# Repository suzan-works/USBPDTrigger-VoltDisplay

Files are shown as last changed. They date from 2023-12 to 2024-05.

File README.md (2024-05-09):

# 電圧表示付き USB PD トリガー
 WCH CH32X035 マイコンを使用して、Vbus電圧をSSD1306 OLEDモジュールに表示する、USB PDトリガーデバイスです。  
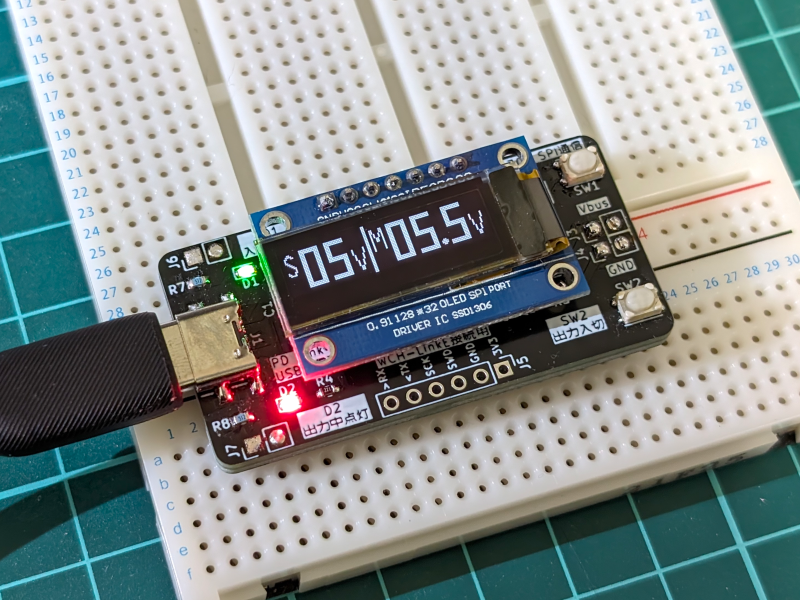
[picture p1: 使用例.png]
使用例
 

# 紹介動画
(https://www.youtube.com/watch?v=RrcGVxVSbrM)

# 操作手順
1. USB-CコネクタにUSB PD電源を接続します。
1. 電圧切替スイッチで出力電圧を変更します。(5→9→12→15→20Vのループ)
1. OLEDディスプレイで希望の電圧が出ていることを確認します。
1. 出力入切スイッチを押すと基板右端のヘッダピンから出力されます。  

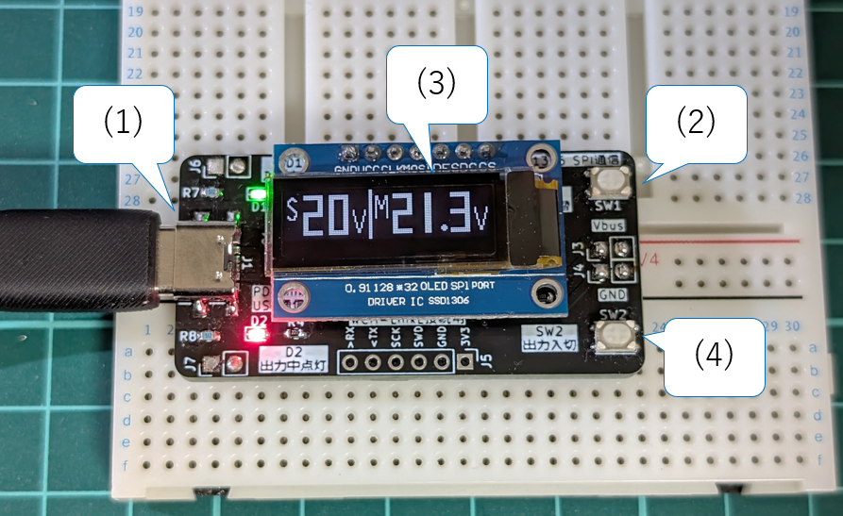
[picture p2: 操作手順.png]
操作手順


# 注意
- 出力電圧はUSB電源(USB PD Source)の仕様に依存します。設定電圧とVbus電圧が乖離する場合があります。
- 表示されるVbus電圧は目安で、測定器としての精度を保証するものではありません。
- 出力電流は1A程度を想定して設計しています。
- このデバイスの使用における損害は一切保証いたしません。自己責任でご使用ください。

# 販売
[boothにて販売中](https://suzan-works.booth.pm/items/5385432)

# マイコン開発
Arduino IDEでのファームウェア変更が可能です。  
WCH LinkEエミュレーターでPCに接続して、「ボードマネージャ」＞「CH32V EVT Boards Support」＞「CH32X035」を選択します。  
参考情報  
https://github.com/openwch/arduino_core_ch32  
https://youtu.be/PSXAfMaWH_A?si=gFLTGL1ydqfZDPP8  

# 設計資料 v1.0
## 回路図
- 回路図 [PDF](回路図.pdf) [KiCanvas](https://kicanvas.org/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)  
- BOM

|Reference|Value|ECサイト|コメント|
|:----|:----|:----|:----|
|U1|マイコン<br>CH32X035G8U6| | |
|U2|三端子レギュレータ<br>NJM78L33SU3|https://akizukidenshi.com/catalog/g/gI-11319/| |
|J1|USB Type-Cコネクタ 電源供給用|https://akizukidenshi.com/catalog/g/gC-16438/|コネクタの固定用ピンをカットして実装しています|
|J2|OLEDディスプレイ<br>SSD1306 SPI 128x32 0.91インチ| | |
|J3, J4, J6, J7|ピンヘッダ 2.54mmピッチ|https://akizukidenshi.com/catalog/g/gC-00167/| |
|J5|WCH-LinkE| | |
|C1, C2|1u/50V/2012|https://akizukidenshi.com/catalog/g/gP-15331/| |
|C3|1u/25V/1608|https://akizukidenshi.com/catalog/g/gP-14526/| |
|R1, R4|220/1608/±5%| | |
|R2|10k/1608/±1%|https://www.marutsu.co.jp/pc/i/857775/| |
|R3|1k/1608/±1%|https://www.marutsu.co.jp/pc/i/857774/| |
|R5|10k/1608/±5%| | |
|R6|22k/1608/±5%| | |
|R7, R8|5.1k/1608/±5%| | |
|D1|緑チップLED<br>SML-E12P8WT86|https://akizukidenshi.com/catalog/g/gI-11878/| |
|D2|赤チップLED<br>SML-E12V8WT86|https://akizukidenshi.com/catalog/g/gI-11879/| |
|F1|ポリスイッチ<br>microSMD010|https://akizukidenshi.com/catalog/g/gP-01316/| |
|Q1, Q2|Pch MOSFET<br>AO3401A|https://akizukidenshi.com/catalog/g/gI-14654/| |
|Q3|抵抗入りトランジスタ<br>DTC143ZU3HZGT106|https://akizukidenshi.com/catalog/g/gI-16746/|基板フットプリントが間違っており無理やり実装しています|
|SW1, SW2|タクトスイッチ<br>SKRPABE010|https://akizukidenshi.com/catalog/g/gP-06184/| |

## プリント基板
- 基板CAD [KiCanvas](https://kicanvas.org/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)
- 外観写真  
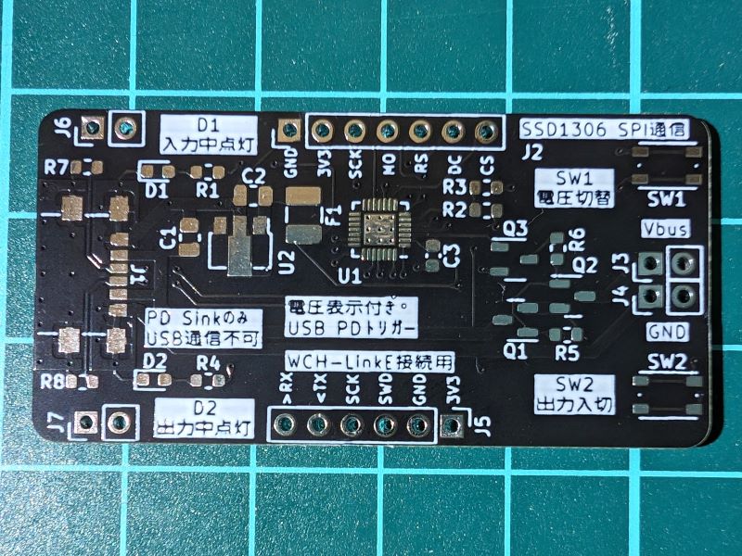
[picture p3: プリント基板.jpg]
プリント基板


## ファームウェア
- ファームウェア [inoファイル](USBPDTrigger-VoltDisplay.ino)

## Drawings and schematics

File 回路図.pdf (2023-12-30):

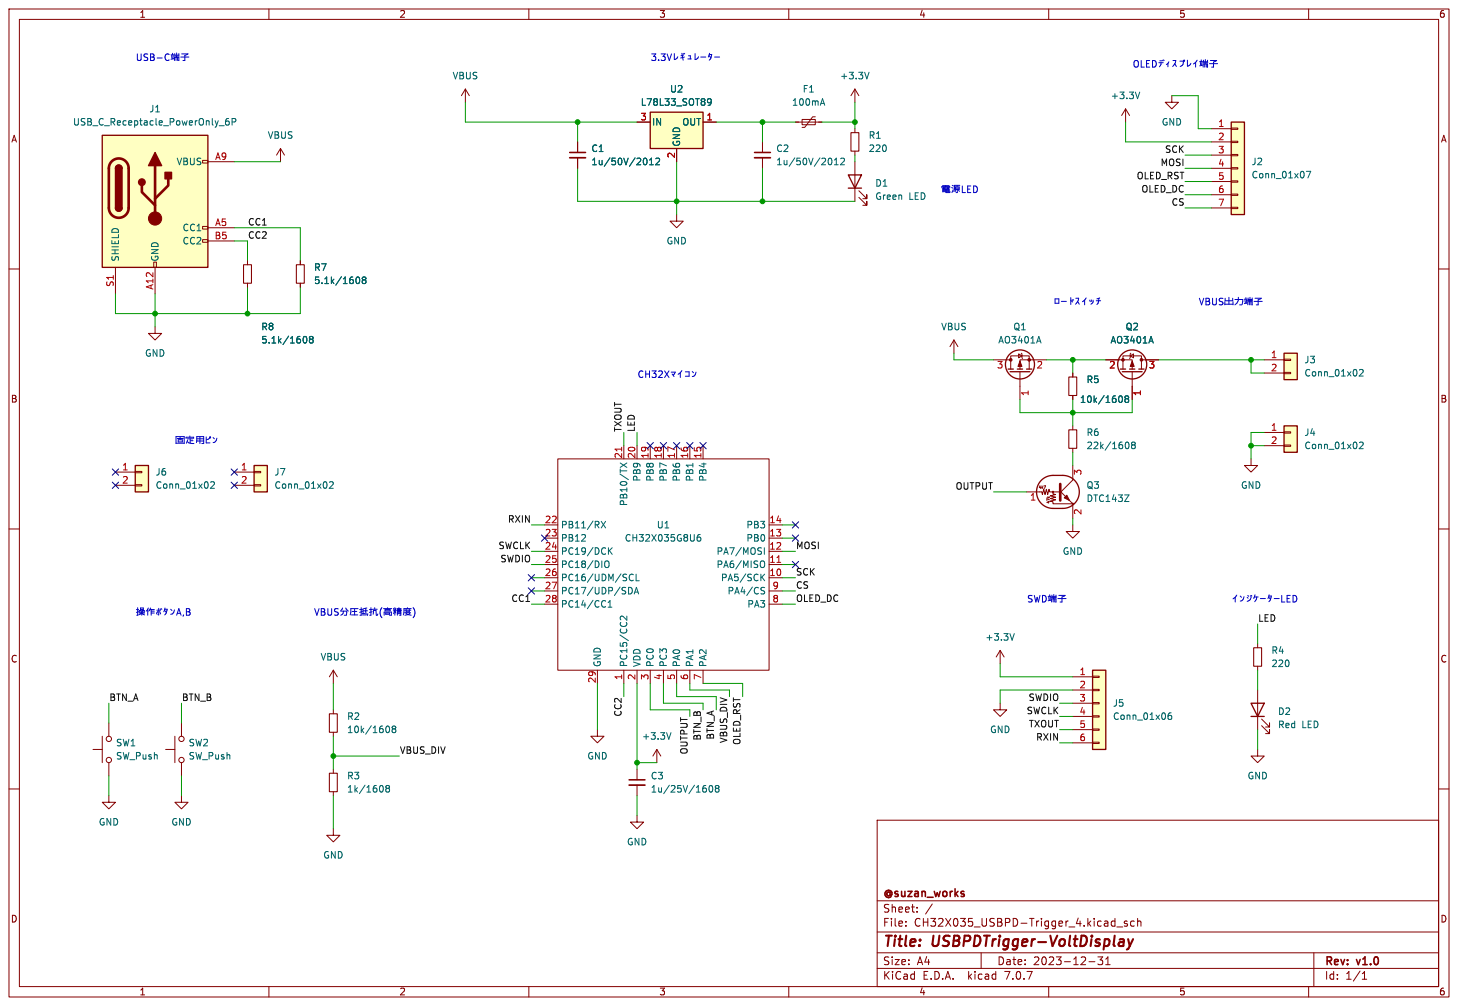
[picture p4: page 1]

2 PB9 20 PB10/TX 21 PB11/RX 22 PB12 23 PC19/DCK 24 PC18/DIO 25 PC16/UDM/SCL 26 PC17/UDP/SDA 27 PC14/CC1 28 GND 29 PC0

PA5/SCK 10 PA6/MISO 11 PA7/MOSI 12 PB0 13 PB3 14 PB4 15 PB1 16 PB6 17 PB7 18 PB8 19 VDD

þÿVBUSRW'bµb—(šØ|¾^¦)
1k/1608 VBUS

Id: 1/1 Title: USBPDTrigger-VoltDisplay

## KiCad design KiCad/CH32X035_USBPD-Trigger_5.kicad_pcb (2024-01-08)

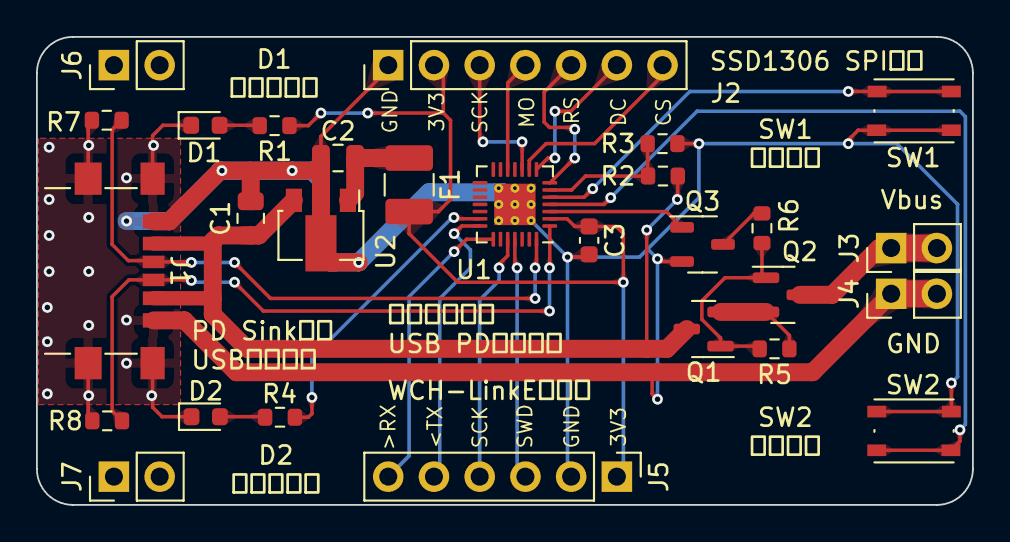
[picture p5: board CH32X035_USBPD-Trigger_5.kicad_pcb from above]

Board: 2 copper layers, 52.0 x 26.0 mm, 28 parts (0 on the bottom side), 26 nets.

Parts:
C1, C2: C_Small; C_0805_2012Metric
C3: C_Small; C_0603_1608Metric
D1, D2: LED; LED_0603_1608Metric
F1: Polyfuse_Small; Fuse_1210_3225Metric_Pad1.42x2.65mm_HandSolder
J1: USB_C_Receptacle_PowerOnly_6P; USB_C_Receptacle_GCT_USB4135-GF-A_6P_TopMnt_Horizontal
J2: Conn_01x07; PinHeader_1x07_P2.54mm_Vertical
J3, J4, J6, J7: Conn_01x02; PinHeader_1x02_P2.54mm_Vertical
J5: Conn_01x06; PinHeader_1x06_P2.54mm_Vertical
Q1, Q2: Q_PMOS_GSD; SOT-23
Q3: DTC143Z; SOT-23-3
R1, R2, R3, R4, R5, R6: R_Small; R_0603_1608Metric
R7, R8: 5.1k; R_0603_1608Metric
SW1, SW2: SW_Push; SW_Push_1P1T_NO_Vertical_Wuerth_434133025816
U1: CH32X035G8U6; QFN-28-1EP_4x4mm_P0.4mm_EP2.3x2.3mm_ThermalVias
U2: L78L33_SOT89; SOT-89-3

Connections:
+3.3V: C3.1, F1.2, J2.2, J5.1, R1.1, U1.2 (VDD)
/BTN_A: SW1.2, U1.5 (PA0)
/BTN_B: SW2.2, U1.4 (PC3)
/CC1: J1.A5 (CC1), R7.1, U1.28 (PC14/CC1)
/CC2: J1.B5 (CC2), R8.1, U1.1 (PC15/CC2)
/CS: J2.7, U1.9 (PA4/CS)
/LED: R4.1, U1.20 (PB9)
/MOSI: J2.4, U1.12 (PA7/MOSI)
/OLED_DC: J2.6, U1.8 (PA3)
/OLED_RST: J2.5, U1.7 (PA2)
/OUTPUT: Q3.1 (B), U1.3 (PC0)
/RXIN: J5.6, U1.22 (PB11/RX)
/SCK: J2.3, U1.10 (PA5/SCK)
/SWCLK: J5.4, U1.24 (PC19/DCK)
/SWDIO: J5.3, U1.25 (PC18/DIO)
/TXOUT: J5.5, U1.21 (PB10/TX)
/VBUS_DIV: R2.2, R3.1, U1.6 (PA1)
GND: C1.2, C2.2, C3.2, D1.1 (K), D2.1 (K), J1.A12 (GND), J1.B12 (GND), J1.S1 (SHIELD), J2.1, J4.1, J4.2, J5.2, Q3.2 (E), R3.2, R7.2, R8.2, SW1.1, SW2.1, U1.29 (GND), U2.2 (GND)
unnamed: D1.2 (A), R1.2
unnamed: D2.2 (A), R4.2
unnamed: J3.1, J3.2, Q2.3 (D)
unnamed: Q1.1 (G), Q2.1 (G), R5.2, R6.1
unnamed: Q1.2 (S), Q2.2 (S), R5.1
unnamed: Q3.3 (C), R6.2
unnamed: C2.1, F1.1, U2.1 (OUT)
VBUS: C1.1, J1.A9 (VBUS), J1.B9 (VBUS), Q1.3 (D), R2.1, U2.3 (IN)

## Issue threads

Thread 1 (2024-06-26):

Can you share the schematic

greenscreenflicker, 2024-06-26:
@suzan-works can you please share the kicad schematic?

suzan-works, 2024-06-26:
[the schematic](https://github.com/suzan-works/USBPDTrigger-VoltDisplay/blob/main/KiCad/CH32X035_USBPD-Trigger_4.kicad_sch) is already available.

suzan-works, 2024-06-26:
You can view the schematic in your browser [here](https://kicanvas.org/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).

greenscreenflicker, 2024-06-28:
@suzan-works thank you, didn't see it!

Closed 2024-06-28.

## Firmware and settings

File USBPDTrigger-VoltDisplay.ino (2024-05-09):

// 電圧表示付き USB PDトリガー
// ファームウェア v1.2
// WCH CH32X035
// 設計 @suzan_works

#include <SPI.h>
#include <usbpd_def.h>
#include <usbpd_sink.h>

uint8_t setVoltage = REQUEST_5v;

// PD出力設定番号、0=5V,1=9V,2=12V,3=15V,4=20V
int pdNum = 0;

#define OLED_CS PA4
#define OLED_DC PA3
#define OLED_RESET PA2

#define btnAPin D0
#define btnBPin D20
#define vbusDividedPin PA1
#define outputPin PC0
#define ledPin D15

bool isLight = 0;
bool isOutput = 0;

float volt = 5.0;

// OLEDディスプレイ表示関連
bool displayData[128][32];
byte convertData[512];
byte reverseData[512];

// SSD1306 Commands
#define SSD1306_DISPLAYOFF 0xAE
#define SSD1306_SETDISPLAYCLOCKDIV 0xD5
#define SSD1306_SETMULTIPLEX 0xA8
#define SSD1306_SETDISPLAYOFFSET 0xD3
#define SSD1306_SETSTARTLINE 0x40
#define SSD1306_CHARGEPUMP 0x8D
#define SSD1306_MEMORYMODE 0x20
#define SSD1306_SEGREMAP 0xA1
#define SSD1306_COMSCANDEC 0xC8
#define SSD1306_SETCOMPINS 0xDA
#define SSD1306_SETCONTRAST 0x81
#define SSD1306_DISPLAYALLON_RESUME 0xA4
#define SSD1306_NORMALDISPLAY 0xA6
#define SSD1306_DISPLAYON 0xAF

// フォントデータ
bool numData[10][32][16] =
	{{{0, 0, 0, 0, 0, 0, 0, 0, 0, 0, 0, 0, 0, 0, 0, 0},
	  {0, 0, 0, 0, 0, 0, 0, 0, 0, 0, 0, 0, 0, 0, 0, 0},
	  {0, 0, 0, 0, 0, 0, 0, 0, 0, 0, 0, 0, 0, 0, 0, 0},
	  {0, 0, 1, 1, 1, 1, 1, 1, 1, 1, 1, 1, 1, 1, 0, 0},
	  {0, 0, 1, 1, 1, 1, 1, 1, 1, 1, 1, 1, 1, 1, 0, 0},
	  {0, 0, 1, 1, 1, 1, 1, 1, 1, 1, 1, 1, 1, 1, 0, 0},
	  {0, 0, 1, 1, 1, 0, 0, 0, 0, 0, 0, 1, 1, 1, 0, 0},
	  {0, 0, 1, 1, 1, 0, 0, 0, 0, 0, 0, 1, 1, 1, 0, 0},
	  {0, 0, 1, 1, 1, 0, 0, 0, 0, 0, 0, 1, 1, 1, 0, 0},
	  {0, 0, 1, 1, 1, 0, 0, 0, 0, 0, 0, 1, 1, 1, 0, 0},
	  {0, 0, 1, 1, 1, 0, 0, 0, 0, 0, 0, 1, 1, 1, 0, 0},
	  {0, 0, 1, 1, 1, 0, 0, 0, 0, 0, 0, 1, 1, 1, 0, 0},
	  {0, 0, 1, 1, 1, 0, 0, 0, 0, 0, 0, 1, 1, 1, 0, 0},
	  {0, 0, 1, 1, 1, 0, 0, 0, 0, 0, 0, 1, 1, 1, 0, 0},
	  {0, 0, 1, 1, 1, 0, 0, 0, 0, 0, 0, 1, 1, 1, 0, 0},
	  {0, 0, 1, 1, 1, 0, 0, 0, 0, 0, 0, 1, 1, 1, 0, 0},
	  {0, 0, 1, 1, 1, 0, 0, 0, 0, 0, 0, 1, 1, 1, 0, 0},
	  {0, 0, 1, 1, 1, 0, 0, 0, 0, 0, 0, 1, 1, 1, 0, 0},
	  {0, 0, 1, 1, 1, 0, 0, 0, 0, 0, 0, 1, 1, 1, 0, 0},
	  {0, 0, 1, 1, 1, 0, 0, 0, 0, 0, 0, 1, 1, 1, 0, 0},
	  {0, 0, 1, 1, 1, 0, 0, 0, 0, 0, 0, 1, 1, 1, 0, 0},
	  {0, 0, 1, 1, 1, 0, 0, 0, 0, 0, 0, 1, 1, 1, 0, 0},
	  {0, 0, 1, 1, 1, 0, 0, 0, 0, 0, 0, 1, 1, 1, 0, 0},
	  {0, 0, 1, 1, 1, 0, 0, 0, 0, 0, 0, 1, 1, 1, 0, 0},
	  {0, 0, 1, 1, 1, 0, 0, 0, 0, 0, 0, 1, 1, 1, 0, 0},
	  {0, 0, 1, 1, 1, 0, 0, 0, 0, 0, 0, 1, 1, 1, 0, 0},
	  {0, 0, 1, 1, 1, 1, 1, 1, 1, 1, 1, 1, 1, 1, 0, 0},
	  {0, 0, 1, 1, 1, 1, 1, 1, 1, 1, 1, 1, 1, 1, 0, 0},
	  {0, 0, 1, 1, 1, 1, 1, 1, 1, 1, 1, 1, 1, 1, 0, 0},
	  {0, 0, 0, 0, 0, 0, 0, 0, 0, 0, 0, 0, 0, 0, 0, 0},
	  {0, 0, 0, 0, 0, 0, 0, 0, 0, 0, 0, 0, 0, 0, 0, 0},
	  {0, 0, 0, 0, 0, 0, 0, 0, 0, 0, 0, 0, 0, 0, 0, 0}},
	 {{0, 0, 0, 0, 0, 0, 0, 0, 0, 0, 0, 0, 0, 0, 0, 0},
	  {0, 0, 0, 0, 0, 0, 0, 0, 0, 0, 0, 0, 0, 0, 0, 0},
	  {0, 0, 0, 0, 0, 0, 0, 0, 0, 0, 0, 0, 0, 0, 0, 0},
	  {0, 0, 0, 0, 0, 0, 1, 1, 1, 1, 0, 0, 0, 0, 0, 0},
	  {0, 0, 0, 0, 0, 0, 1, 1, 1, 1, 0, 0, 0, 0, 0, 0},
	  {0, 0, 0, 0, 0, 0, 1, 1, 1, 1, 0, 0, 0, 0, 0, 0},
	  {0, 0, 0, 0, 0, 0, 1, 1, 1, 1, 0, 0, 0, 0, 0, 0},
	  {0, 0, 0, 0, 0, 0, 1, 1, 1, 1, 0, 0, 0, 0, 0, 0},
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

bool sData[32][10] =
	{
		{0, 0, 0, 0, 0, 0, 0, 0, 0, 0},
		{0, 0, 0, 0, 0, 0, 0, 0, 0, 0},
		{0, 0, 0, 0, 0, 0, 0, 0, 0, 0},
		{0, 0, 0, 0, 0, 0, 0, 0, 0, 0},
		{0, 0, 0, 0, 1, 1, 0, 0, 0, 0},
		{0, 0, 0, 1, 1, 1, 1, 0, 0, 0},
		{0, 0, 1, 1, 0, 0, 1, 1, 0, 0},
		{0, 0, 1, 0, 0, 0, 0, 0, 0, 0},
		{0, 0, 1, 0, 0, 0, 0, 0, 0, 0},
		{0, 0, 1, 1, 0, 0, 0, 0, 0, 0},
		{0, 0, 0, 1, 1, 0, 0, 0, 0, 0},
		{0, 0, 0, 0, 1, 1, 0, 0, 0, 0},
		{0, 0, 0, 0, 0, 1, 1, 0, 0, 0},
		{0, 0, 0, 0, 0, 0, 1, 1, 0, 0},
		{0, 0, 0, 0, 0, 0, 0, 1, 0, 0},
		{0, 0, 0, 0, 0, 0, 0, 1, 0, 0},
		{0, 0, 1, 0, 0, 0, 1, 1, 0, 0},
		{0, 0, 1, 1, 0, 0, 1, 0, 0, 0},
		{0, 0, 0, 1, 1, 1, 1, 0, 0, 0},
		{0, 0, 0, 0, 0, 0, 0, 0, 0, 0},
		{0, 0, 0, 0, 0, 0, 0, 0, 0, 0},
		{0, 0, 0, 0, 0, 0, 0, 0, 0, 0},
		{0, 0, 0, 0, 0, 0, 0, 0, 0, 0},
		{0, 0, 0, 0, 0, 0, 0, 0, 0, 0},
		{0, 0, 0, 0, 0, 0, 0, 0, 0, 0},
		{0, 0, 0, 0, 0, 0, 0, 0, 0, 0},
		{0, 0, 0, 0, 0, 0, 0, 0, 0, 0},
		{0, 0, 0, 0, 0, 0, 0, 0, 0, 0},
		{0, 0, 0, 0, 0, 0, 0, 0, 0, 0},
		{0, 0, 0, 0, 0, 0, 0, 0, 0, 0},
		{0, 0, 0, 0, 0, 0, 0, 0, 0, 0},
		{0, 0, 0, 0, 0, 0, 0, 0, 0, 0}};

bool mData[32][10] =
	{
		{0, 0, 0, 0, 0, 0, 0, 0, 0, 0},
		{0, 0, 0, 0, 0, 0, 0, 0, 0, 0},
		{0, 0, 0, 0, 0, 0, 0, 0, 0, 0},
		{0, 0, 0, 0, 0, 0, 0, 0, 0, 0},
		{0, 1, 1, 0, 0, 0, 0, 1, 1, 0},
		{0, 1, 1, 0, 0, 0, 0, 1, 1, 0},
		{0, 1, 1, 0, 0, 0, 0, 1, 1, 0},
		{0, 1, 0, 1, 0, 0, 1, 0, 1, 0},
		{0, 1, 0, 1, 0, 0, 1, 0, 1, 0},
		{0, 1, 0, 1, 0, 0, 1, 0, 1, 0},
		{0, 1, 0, 0, 1, 1, 0, 0, 1, 0},
		{0, 1, 0, 0, 1, 1, 0, 0, 1, 0},
		{0, 1, 0, 0, 1, 1, 0, 0, 1, 0},
		{0, 1, 0, 0, 0, 0, 0, 0, 1, 0},
		{0, 1, 0, 0, 0, 0, 0, 0, 1, 0},
		{0, 1, 0, 0, 0, 0, 0, 0, 1, 0},
		{0, 1, 0, 0, 0, 0, 0, 0, 1, 0},
		{0, 1, 0, 0, 0, 0, 0, 0, 1, 0},
		{0, 1, 0, 0, 0, 0, 0, 0, 1, 0},
		{0, 0, 0, 0, 0, 0, 0, 0, 0, 0},
		{0, 0, 0, 0, 0, 0, 0, 0, 0, 0},
		{0, 0, 0, 0, 0, 0, 0, 0, 0, 0},
		{0, 0, 0, 0, 0, 0, 0, 0, 0, 0},
		{0, 0, 0, 0, 0, 0, 0, 0, 0, 0},
		{0, 0, 0, 0, 0, 0, 0, 0, 0, 0},
		{0, 0, 0, 0, 0, 0, 0, 0, 0, 0},
		{0, 0, 0, 0, 0, 0, 0, 0, 0, 0},
		{0, 0, 0, 0, 0, 0, 0, 0, 0, 0},
		{0, 0, 0, 0, 0, 0, 0, 0, 0, 0},
		{0, 0, 0, 0, 0, 0, 0, 0, 0, 0},
		{0, 0, 0, 0, 0, 0, 0, 0, 0, 0},
		{0, 0, 0, 0, 0, 0, 0, 0, 0, 0}};

bool vData[32][10] =
	{
		{0, 0, 0, 0, 0, 0, 0, 0, 0, 0},
		{0, 0, 0, 0, 0, 0, 0, 0, 0, 0},
		{0, 0, 0, 0, 0, 0, 0, 0, 0, 0},
		{0, 0, 0, 0, 0, 0, 0, 0, 0, 0},
		{0, 0, 0, 0, 0, 0, 0, 0, 0, 0},
		{0, 0, 0, 0, 0, 0, 0, 0, 0, 0},
		{0, 0, 0, 0, 0, 0, 0, 0, 0, 0},
		{0, 0, 0, 0, 0, 0, 0, 0, 0, 0},
		{0, 0, 0, 0, 0, 0, 0, 0, 0, 0},
		{0, 0, 0, 0, 0, 0, 0, 0, 0, 0},
		{0, 0, 0, 0, 0, 0, 0, 0, 0, 0},
		{0, 0, 0, 0, 0, 0, 0, 0, 0, 0},
		{0, 0, 0, 0, 0, 0, 0, 0, 0, 0},
		{0, 1, 0, 0, 0, 0, 0, 0, 1, 0},
		{0, 1, 0, 0, 0, 0, 0, 0, 1, 0},
		{0, 1, 0, 0, 0, 0, 0, 0, 1, 0},
		{0, 1, 0, 0, 0, 0, 0, 0, 1, 0},
		{0, 0, 1, 0, 0, 0, 0, 1, 0, 0},
		{0, 0, 1, 0, 0, 0, 0, 1, 0, 0},
		{0, 0, 1, 0, 0, 0, 0, 1, 0, 0},
		{0, 0, 1, 0, 0, 0, 0, 1, 0, 0},
		{0, 0, 0, 1, 0, 0, 1, 0, 0, 0},
		{0, 0, 0, 1, 0, 0, 1, 0, 0, 0},
		{0, 0, 0, 1, 0, 0, 1, 0, 0, 0},
		{0, 0, 0, 1, 0, 0, 1, 0, 0, 0},
		{0, 0, 0, 0, 1, 1, 0, 0, 0, 0},
		{0, 0, 0, 0, 1, 1, 0, 0, 0, 0},
		{0, 0, 0, 0, 1, 1, 0, 0, 0, 0},
		{0, 0, 0, 0, 0, 0, 0, 0, 0, 0},
		{0, 0, 0, 0, 0, 0, 0, 0, 0, 0},
		{0, 0, 0, 0, 0, 0, 0, 0, 0, 0},
		{0, 0, 0, 0, 0, 0, 0, 0, 0, 0}};

bool barData[32][4] =
	{
		{0, 1, 1, 0},
		{0, 1, 1, 0},
		{0, 1, 1, 0},
		{0, 1, 1, 0},
		{0, 1, 1, 0},
		{0, 1, 1, 0},
		{0, 1, 1, 0},
		{0, 1, 1, 0},
		{0, 1, 1, 0},
		{0, 1, 1, 0},
		{0, 1, 1, 0},
		{0, 1, 1, 0},
		{0, 1, 1, 0},
		{0, 1, 1, 0},
		{0, 1, 1, 0},
		{0, 1, 1, 0},
		{0, 1, 1, 0},
		{0, 1, 1, 0},
		{0, 1, 1, 0},
		{0, 1, 1, 0},
		{0, 1, 1, 0},
		{0, 1, 1, 0},
		{0, 1, 1, 0},
		{0, 1, 1, 0},
		{0, 1, 1, 0},
		{0, 1, 1, 0},
		{0, 1, 1, 0},
		{0, 1, 1, 0},
		{0, 1, 1, 0},
		{0, 1, 1, 0},
		{0, 1, 1, 0},
		{0, 1, 1, 0}};

bool pointData[32][4] =
	{
		{0, 0, 0, 0},
		{0, 0, 0, 0},
		{0, 0, 0, 0},
		{0, 0, 0, 0},
		{0, 0, 0, 0},
		{0, 0, 0, 0},
		{0, 0, 0, 0},
		{0, 0, 0, 0},
		{0, 0, 0, 0},
		{0, 0, 0, 0},
		{0, 0, 0, 0},
		{0, 0, 0, 0},
		{0, 0, 0, 0},
		{0, 0, 0, 0},
		{0, 0, 0, 0},
		{0, 0, 0, 0},
		{0, 0, 0, 0},
		{0, 0, 0, 0},
		{0, 0, 0, 0},
		{0, 0, 0, 0},
		{0, 0, 0, 0},
		{0, 0, 0, 0},
		{0, 0, 0, 0},
		{0, 0, 0, 0},
		{0, 1, 1, 0},
		{1, 1, 1, 1},
		{1, 1, 1, 1},
		{0, 1, 1, 0},
		{0, 0, 0, 0},
		{0, 0, 0, 0},
		{0, 0, 0, 0},
		{0, 0, 0, 0}};

// 数値を表示データに変換する
void floatToDisplayData(float value, int pdNum)
{
	int tens = int(value) / 10;		  // Extract the tens digit.
	int ones = int(value) % 10;		  // Extract the ones digit.
	int tenth = int(value * 10) % 10; // Extract the tenth place digit after the decimal.

	// Populate displayData using numData.
	for (int y = 0; y < 32; y++)
	{
		for (int x = 0; x < 128; x++)
		{
			if ((x >= 0) && (x < 10))
			{
				displayData[x][y] = sData[y][x];
			}
			if ((x >= 10) && (x < 26))
			{
				switch (pdNum)
				{
				case 0:
					displayData[x][y] = numData[0][y][(x - 10)];
					break;
				case 1:
					displayData[x][y] = numData[0][y][(x - 10)];
					break;
				case 2:
					displayData[x][y] = numData[1][y][(x - 10)];
					break;
				case 3:
					displayData[x][y] = numData[1][y][(x - 10)];
					break;
				case 4:
					displayData[x][y] = numData[2][y][(x - 10)];
					break;

				default:
					break;
				}
			}
			if ((x >= 26) && (x < 42))
			{
				switch (pdNum)
				{
				case 0:
					displayData[x][y] = numData[5][y][(x - 26)];
					break;
				case 1:
					displayData[x][y] = numData[9][y][(x - 26)];
					break;
				case 2:
					displayData[x][y] = numData[2][y][(x - 26)];
					break;
				case 3:
					displayData[x][y] = numData[5][y][(x - 26)];
					break;
				case 4:
					displayData[x][y] = numData[0][y][(x - 26)];
					break;

				default:
					break;
				}
			}
			if ((x >= 42) && (x < 52))
			{
				displayData[x][y] = vData[y][(x - 42)];
			}
			if ((x >= 52) && (x < 56))
			{
				displayData[x][y] = barData[y][(x - 52)];
			}
			if ((x >= 56) && (x < 66))
			{
				displayData[x][y] = mData[y][(x - 56)];
			}
			if ((x >= 66) && (x < 82))
			{
				displayData[x][y] = numData[tens][y][(x - 66)];
			}
			if ((x >= 82) && (x < 98))
			{
				displayData[x][y] = numData[ones][y][(x - 82)];
			}
			if ((x >= 98) && (x < 102))
			{
				displayData[x][y] = pointData[y][(x - 98)];
			}
			if ((x >= 102) && (x < 118))
			{
				displayData[x][y] = numData[tenth][y][(x - 102)];
			}
			if ((x >= 118) && (x < 128))
			{
				displayData[x][y] = vData[y][(x - 118)];
			}
		}
	}
}

// SPI送信データに変換する
void displayToConvertData()
{
	for (int x = 0; x < 128; x++)
	{
		for (int yByte = 0; yByte < 4; yByte++)
		{
			convertData[x + (yByte * 128)] = 0;
			for (int bit = 0; bit < 8; bit++)
			{
				if (displayData[x][bit + (yByte * 8)])
				{
					convertData[x + (yByte * 128)] |= (1 << bit);
				}
			}
		}
	}
}

// データ変換
void convertToReverseData()
{
	for (int i = 0; i < 512; i++)
	{
		reverseData[i] = ((convertData[i] & 0b00000001) << 7) |
						 ((convertData[i] & 0b00000010) << 5) |
						 ((convertData[i] & 0b00000100) << 3) |
						 ((convertData[i] & 0b00001000) << 1) |
						 ((convertData[i] & 0b00010000) >> 1) |
						 ((convertData[i] & 0b00100000) >> 3) |
						 ((convertData[i] & 0b01000000) >> 5) |
						 ((convertData[i] & 0b10000000) >> 7);
	}
}

// SPI送信
void sendCommand(uint8_t command)
{
	digitalWrite(OLED_DC, LOW);	 // Command mode
	SPI.transfer(command);		 // Send command byte
	digitalWrite(OLED_DC, HIGH); // Data mode
}

// ボタンチャタリング防止用の変数
unsigned long currentTime = 0;
unsigned long previousTime = 0;
const unsigned long interval = 80; // 判定間隔(ミリ秒)
bool btnAState = 1;
bool btnBState = 1;
bool previousBtnAState = 1;
bool previousBtnBState = 1;
int previousPdNum = 0;
int voltRead = 0;

void setup()
{
	pinMode(OLED_CS, OUTPUT);
	pinMode(OLED_DC, OUTPUT);
	pinMode(OLED_RESET, OUTPUT);

	pinMode(btnAPin, INPUT_PULLUP);
	pinMode(btnBPin, INPUT_PULLUP);
	pinMode(vbusDividedPin, INPUT);
	pinMode(outputPin, OUTPUT);
	pinMode(ledPin, OUTPUT);
	digitalWrite(outputPin, isOutput);
	digitalWrite(ledPin, isLight);

	Serial.begin(115200);
	Serial.println("setup");

	usbpd_sink_init();

	SPI.begin();

	// OLEDリセット
	digitalWrite(OLED_RESET, LOW);
	delay(10);
	digitalWrite(OLED_RESET, HIGH);
	delay(10);

	// SPI通信設定
	SPI.beginTransaction(SPISettings(100000, MSBFIRST, SPI_MODE0));
	digitalWrite(OLED_CS, LOW); // Enable OLED by setting CS to LOW

	// OLEDイニシャルコマンド
	sendCommand(SSD1306_DISPLAYOFF);
	sendCommand(SSD1306_SETDISPLAYCLOCKDIV);
	sendCommand(0x80);
	sendCommand(SSD1306_SETMULTIPLEX);
	sendCommand(0x1F);
	sendCommand(SSD1306_SETDISPLAYOFFSET);
	sendCommand(0x0);
	sendCommand(SSD1306_SETSTARTLINE);
	sendCommand(SSD1306_CHARGEPUMP);
	sendCommand(0x14);
	sendCommand(SSD1306_MEMORYMODE);
	sendCommand(0x00);
	sendCommand(SSD1306_SEGREMAP);
	sendCommand(SSD1306_COMSCANDEC);
	sendCommand(SSD1306_SETCOMPINS);
	sendCommand(0x02);
	sendCommand(SSD1306_SETCONTRAST);
	sendCommand(0x8F);
	sendCommand(SSD1306_DISPLAYALLON_RESUME);
	sendCommand(SSD1306_NORMALDISPLAY);
	sendCommand(SSD1306_DISPLAYON);

	digitalWrite(OLED_CS, HIGH);
	SPI.endTransaction();
}

void loop()
{
	// ボタンチャタリング防止、ディスプレイちらつき防止
	currentTime = millis();
	if ((currentTime - previousTime) >= interval)
	{
		previousTime = currentTime;
		previousBtnAState = btnAState;
		previousBtnBState = btnBState;		
		btnAState = digitalRead(btnAPin);
		btnBState = digitalRead(btnBPin);

		// 電圧読み取りサンプルを取得して平均値を計算
		int sum = 0;
		for (int i = 0; i < 10; i++)
		{
			sum += analogRead(vbusDividedPin);
			delay(1); // 必要に応じて遅延を追加
		}
		voltRead = sum / 10; 
	}

	if ((previousBtnAState == 0)&&(btnAState == 0))
	{
		//Serial.println("btnA");
		btnAState = 1;
		pdNum = (pdNum + 1) % 5;
		isOutput = 0;
		isLight = 0;
	}

	if ((previousBtnBState == 0)&&(btnBState == 0))
	{
		//Serial.println("btnB");
		btnBState = 1;
		isOutput = !isOutput;
		isLight = !isLight;
	}

	if (pdNum != previousPdNum)
	{
		//Serial.println("pdNum");

		switch (pdNum)
		{
		case 0:
			setVoltage = REQUEST_5v;
			break;
		case 1:
			setVoltage = REQUEST_9v;
			break;
		case 2:
			setVoltage = REQUEST_12v;
			break;
		case 3:
			setVoltage = REQUEST_15v;
			break;
		case 4:
			setVoltage = REQUEST_20v;
			break;

		default:
			break;
		}

		if (usbpd_sink_get_ready())
		{
			usbpd_sink_set_request_fixed_voltage(setVoltage);
		}

		previousPdNum = pdNum;
	}
	
	digitalWrite(outputPin, isOutput);
	digitalWrite(ledPin, isLight);

	// 12bit
	float result = (float)voltRead / 4095;
	// 1k/10k分圧、現物合わせで表示値調整
	volt = (11 * 3.3 * result) * 0.9465 - 0.0989;

	// OLED表示
	SPI.beginTransaction(SPISettings(100000, MSBFIRST, SPI_MODE0));
	digitalWrite(OLED_CS, LOW);	 // Enable OLED
	digitalWrite(OLED_DC, HIGH); // Data mode

	floatToDisplayData(volt, pdNum);
	displayToConvertData();
	convertToReverseData();

	for (int i = 0; i < 512; i++)
	{
		SPI.transfer(convertData[i]);
	}

	digitalWrite(OLED_CS, HIGH); // Disable OLED
	SPI.endTransaction();		 // End the SPI transaction
}

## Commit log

2023-12-30 ファイルアップロード
2023-12-30 README追記
2024-01-08 BOM追記
2024-01-08 KiCadファイル追加
    [CH32X035_USBPD-Trigger_4.kicad_sch, CH32X035_USBPD-Trigger_5.kicad_pcb]
2024-01-08 KiCanvas表示追加
2024-03-10 動作改善のためのファームウェア更新
    ・ボタン入力のチャタリング防止
    ・表示電圧を現物合わせで調整
    上記を実装しました。
2024-05-09 ファームウェア更新とREADME追記
    ・ファームウェア：電圧測定に平均化処理を追加
    ・README：紹介動画と販売場所のリンクを追記
